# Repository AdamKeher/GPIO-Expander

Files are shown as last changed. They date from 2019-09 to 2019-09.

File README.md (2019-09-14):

# GPIO Expander
An I2C controlled, breadboard friendly GPIO exansion board based on the Texas Instruments PCF8574 with builtin buttons and LED's for prototyping.
## PCB Layout
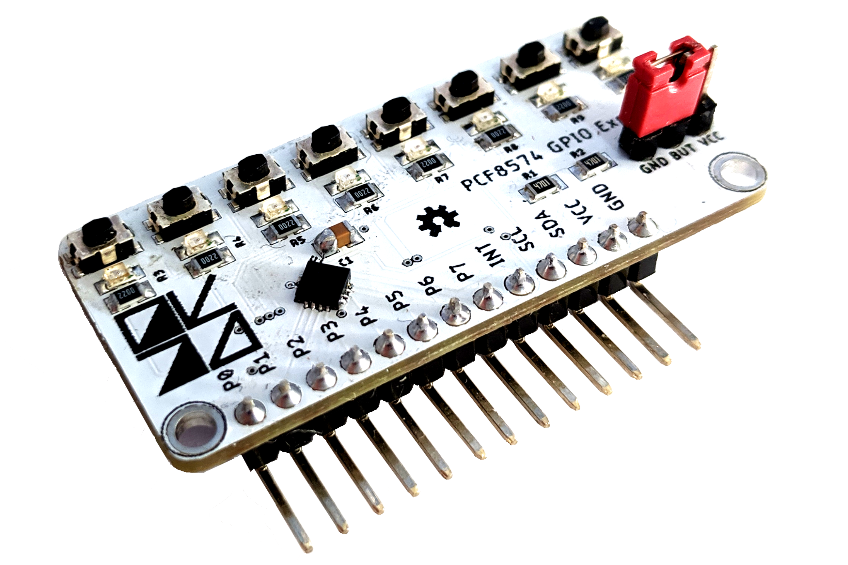
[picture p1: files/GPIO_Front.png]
GPIO Expander Board Image

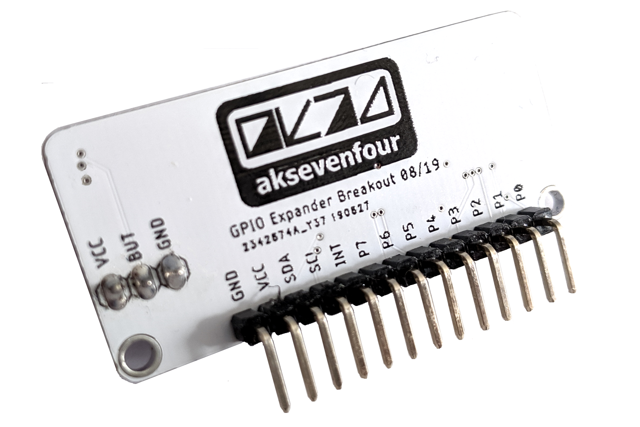
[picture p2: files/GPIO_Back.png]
GPIO Expander Board Image

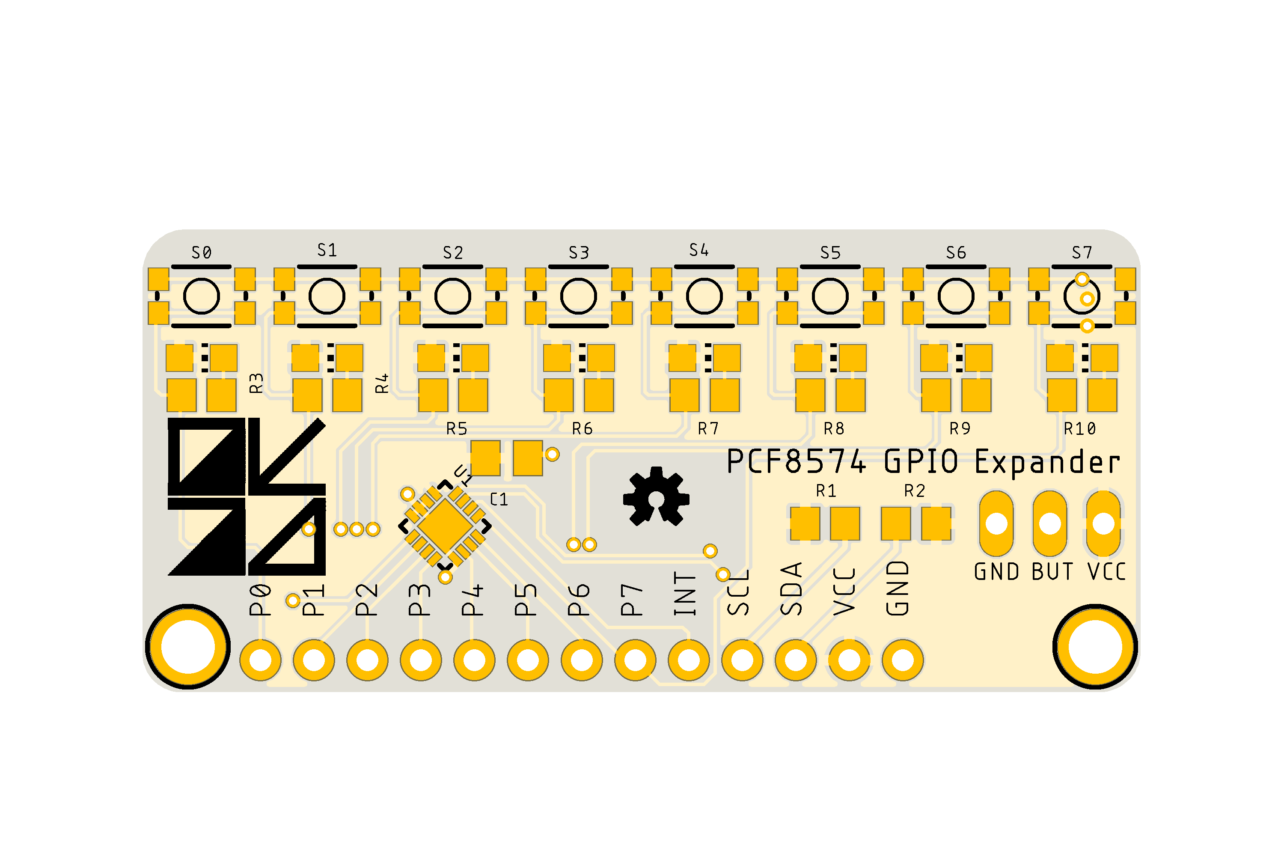
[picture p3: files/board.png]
GPIO Expander Board Image

## About
The PCF8574 device provides general-purpose remote I/O expansion for most microcontroller families by way of the I2C interface (serial clock(SCL), serial data (SDA)].
The device features an 8-bit quasi-bidirectional I/O port (P0–P7), including latched outputs with highcurrent drive capability for directly driving LEDs. Each quasi-bidirectional I/O can be used as an input or output without the use of a data-direction control signal. At power on, the I/Os are high. In this mode, only a current source to VCC is active.

The board has builtin buttons and LED's to help quickly prototype solutions and is able to be mounted either vertically or horizontally.

A switchable jumper is provided to connect all tactiles switches to VCC or to GND.
## Features
* 2.5V to 6.0V operation
* Arduino Library
* 8 Builtin tactile switches
* 8 Builtin controllable LED's
* Breadboard friendly
* Based on the popular PCF8574 I2C IC
* Low Standby-Current Consumption of 10 μA Max
* Open-Drain Interrupt Output
* Compatible With Most Microcontrollers
* Latched Outputs With High-Current Drive
* Single Maskable output register for all IO ports

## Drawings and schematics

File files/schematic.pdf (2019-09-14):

# Button Header VCC

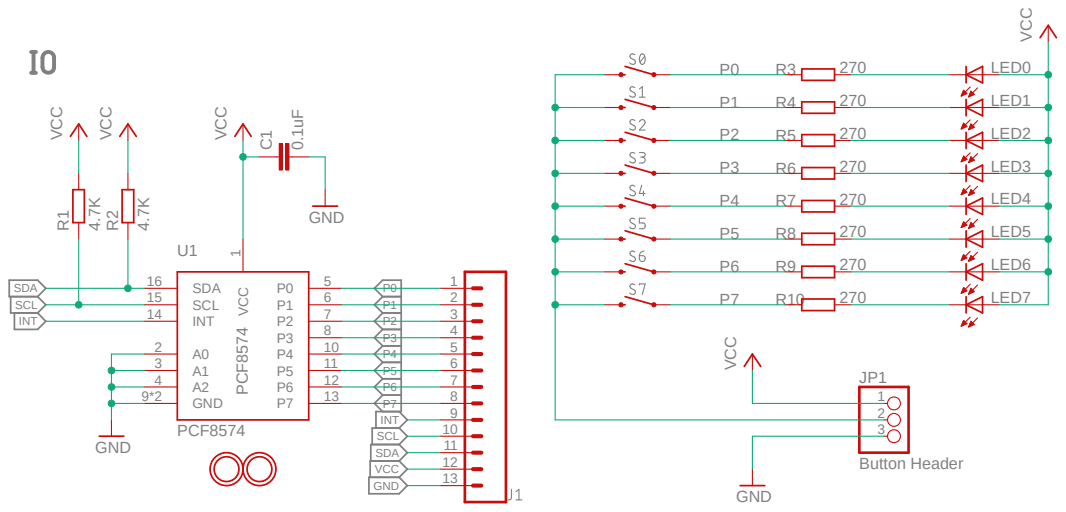
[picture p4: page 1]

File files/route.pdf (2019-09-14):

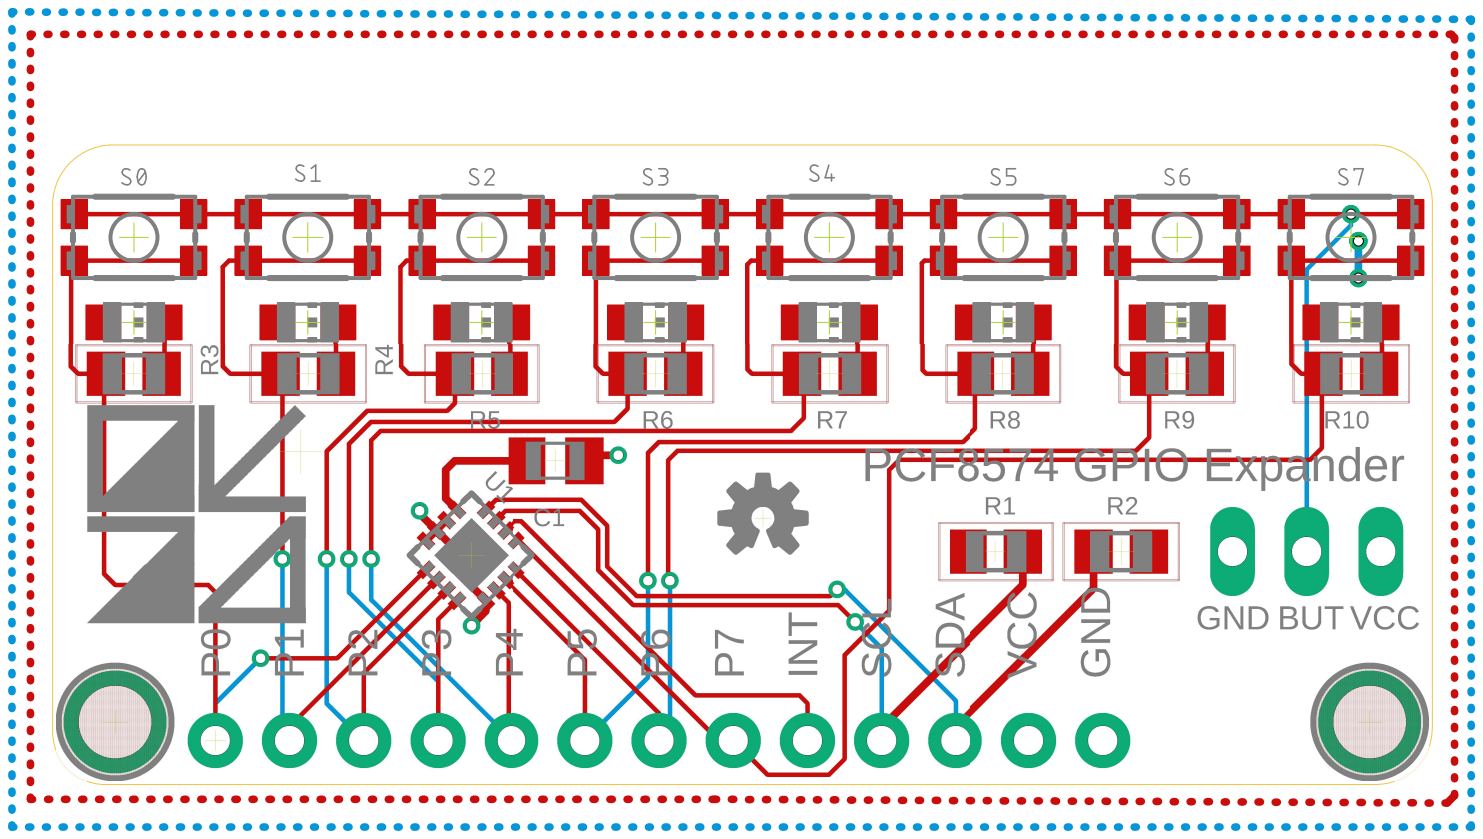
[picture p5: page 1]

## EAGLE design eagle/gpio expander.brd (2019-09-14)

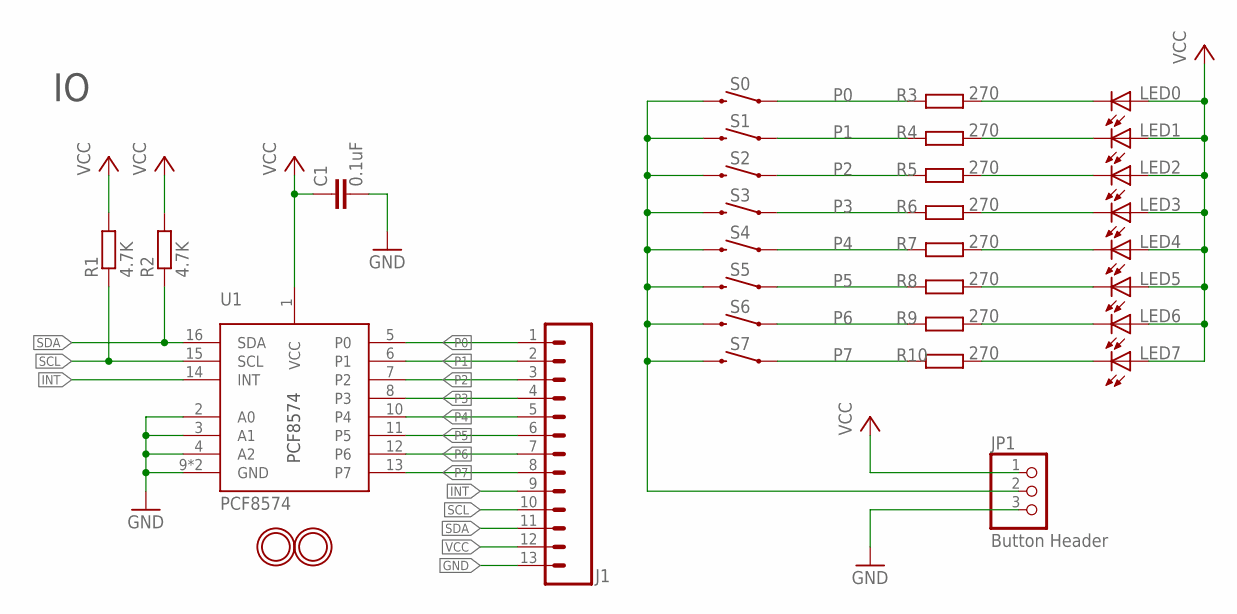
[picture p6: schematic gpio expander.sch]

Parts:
C1: 0.1uF; C0805K
J1: GPIO Expander Pins; 1X13_NO_SILK
JP1: Button Header; 1X03
LED0, LED1, LED2, LED3, LED4, LED5, LED6, LED7: GREEN; CHIP-LED0805
MH1, MH3: MOUNTINGHOLE2.5; MOUNTINGHOLE_2.5_PLATED
R1, R2: 4.7K; R0805
R3, R4, R5, R6, R7, R8, R9, R10: 270; R0805
S0, S1, S2, S3, S4, S5, S6, S7: MOMENTARY-SWITCH-SPST-SMD-4.6X2.8MM; TACTILE_SWITCH_SMD_4.6X2.8MM
U1: PCF8574; QFN-16-3MM

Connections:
GND: C1.2, J1.13, JP1.3, U1.2 (A0), U1.3 (A1), U1.4 (A2), U1.9 (GND), U1.P$1 (GND)
INT: J1.9, U1.14 (INT)
unnamed: JP1.2, S0.3 (2), S0.4 (2), S1.3 (2), S1.4 (2), S2.3 (2), S2.4 (2), S3.3 (2), S3.4 (2), S4.3 (2), S4.4 (2), S5.3 (2), S5.4 (2), S6.3 (2), S6.4 (2), S7.3 (2), S7.4 (2)
unnamed: LED0.C, R3.1
unnamed: LED1.C, R4.1
unnamed: LED2.C, R5.1
unnamed: LED3.C, R6.1
unnamed: LED4.C, R7.1
unnamed: LED5.C, R8.1
unnamed: LED6.C, R9.1
unnamed: LED7.C, R10.1
P0: J1.1, R3.2, S0.1, S0.2 (1), U1.5 (P0)
P1: J1.2, R4.2, S1.1, S1.2 (1), U1.6 (P1)
P2: J1.3, R5.2, S2.1, S2.2 (1), U1.7 (P2)
P3: J1.4, R6.2, S3.1, S3.2 (1), U1.8 (P3)
P4: J1.5, R7.2, S4.1, S4.2 (1), U1.10 (P4)
P5: J1.6, R8.2, S5.1, S5.2 (1), U1.11 (P5)
P6: J1.7, R9.2, S6.1, S6.2 (1), U1.12 (P6)
P7: J1.8, R10.2, S7.1, S7.2 (1), U1.13 (P7)
SCL: J1.10, R1.1, U1.15 (SCL)
SDA: J1.11, R2.1, U1.16 (SDA)
VCC: C1.1, J1.12, JP1.1, LED0.A, LED1.A, LED2.A, LED3.A, LED4.A, LED5.A, LED6.A, LED7.A, R1.2, R2.2, U1.1 (VCC)

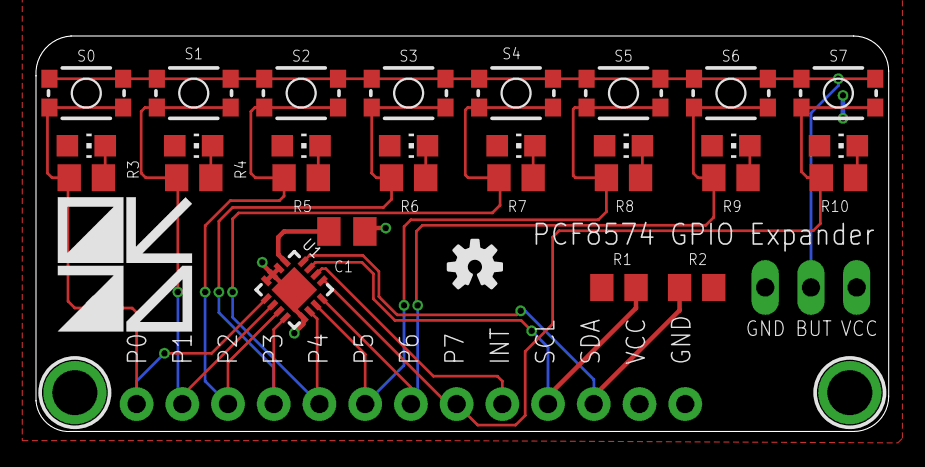
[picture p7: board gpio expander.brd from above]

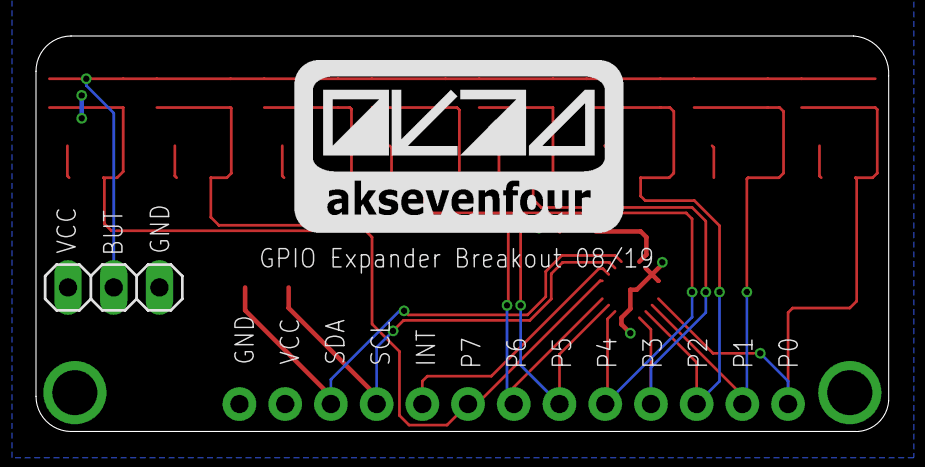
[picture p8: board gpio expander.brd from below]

Board: 2 copper layers, 47.4 x 22.0 mm, 35 parts (2 on the bottom side), 22 nets.

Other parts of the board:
U$1: AK74_LOGO_MEDIUM
U$2: AK74_LOGO_MEDIUM_TEXTONLY_SQUARE
U$3: OSHW-LOGO-S

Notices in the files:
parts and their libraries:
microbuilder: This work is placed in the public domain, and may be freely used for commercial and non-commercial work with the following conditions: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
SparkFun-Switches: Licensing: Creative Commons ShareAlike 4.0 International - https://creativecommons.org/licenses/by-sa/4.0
